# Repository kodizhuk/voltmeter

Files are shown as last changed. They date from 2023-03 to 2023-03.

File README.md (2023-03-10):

# Voltmeter for the power supply
Simple voltmeter on the DA14858 microcontroller
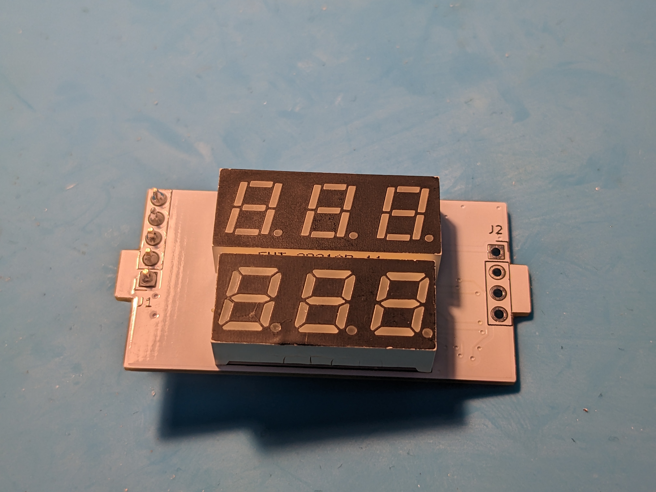
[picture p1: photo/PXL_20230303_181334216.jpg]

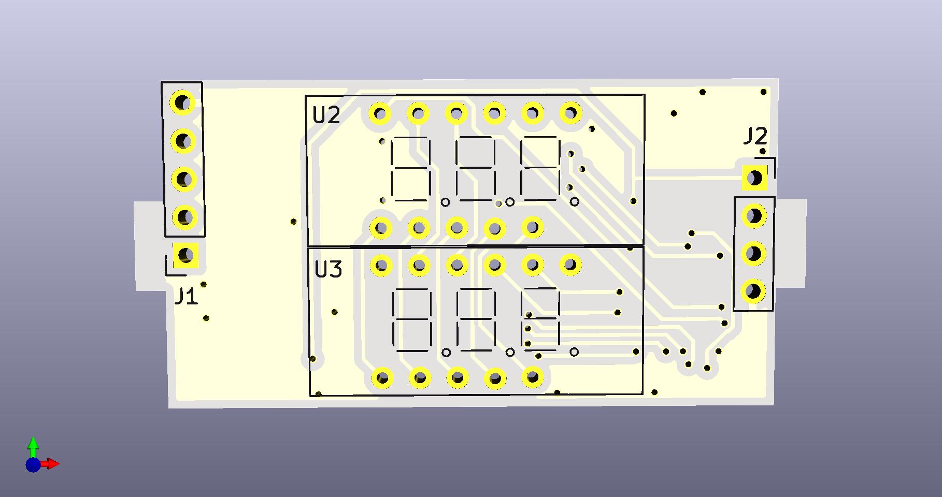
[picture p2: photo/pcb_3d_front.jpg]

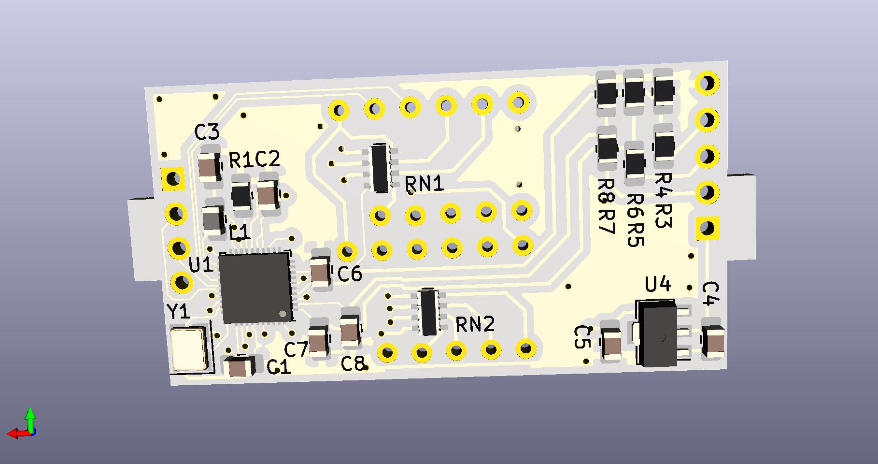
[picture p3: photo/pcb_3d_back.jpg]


## Short description
The three channels ADC are used to measure voltage, current and the potentiometer value (that changed the current limit). The voltage and current are displayed if the potentiometer value isn't changing. If the potentiomter values is changed, the current limit value is displayed instead of the current.

## Schematic
PCB is created using KiKad software
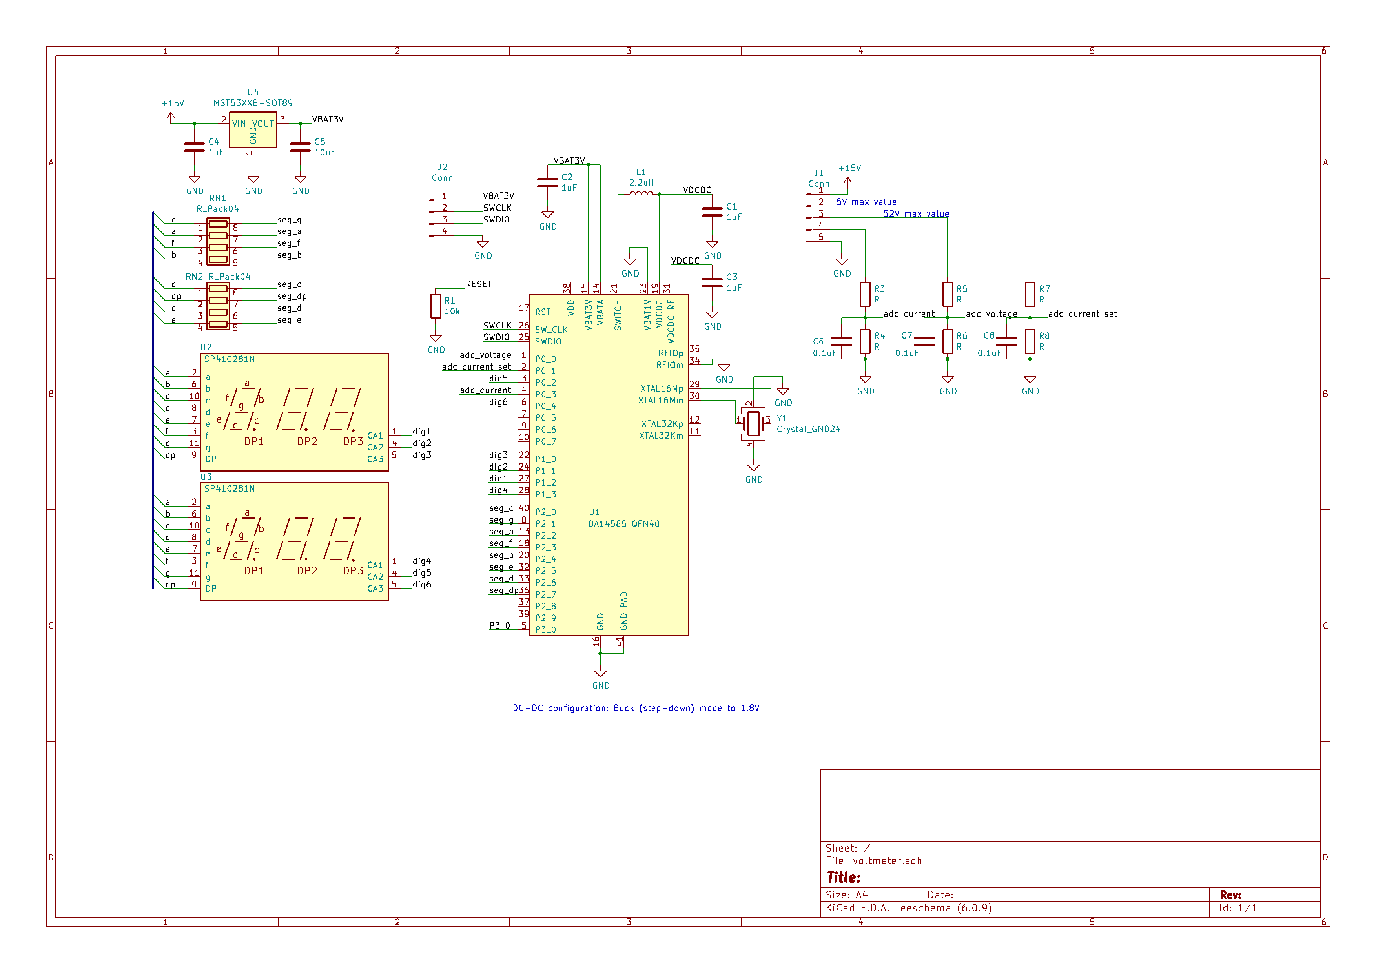
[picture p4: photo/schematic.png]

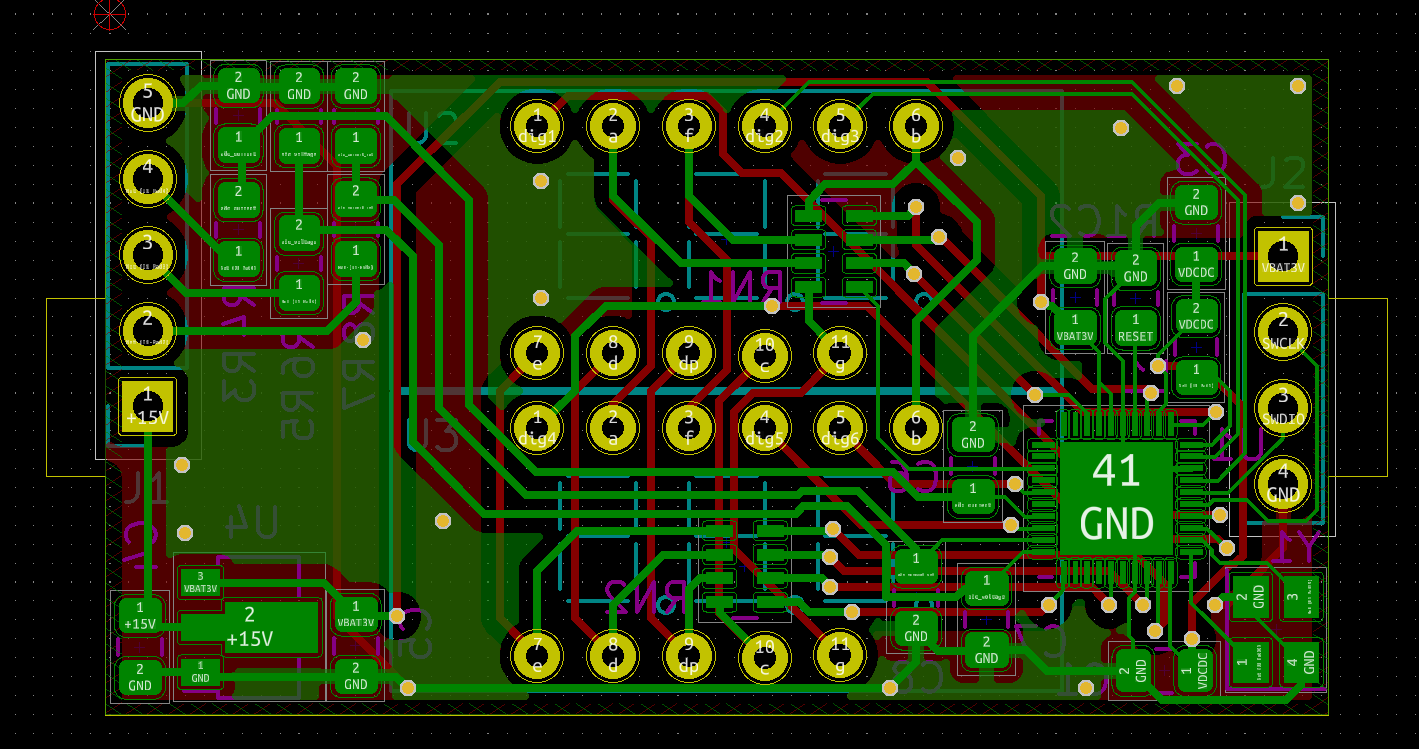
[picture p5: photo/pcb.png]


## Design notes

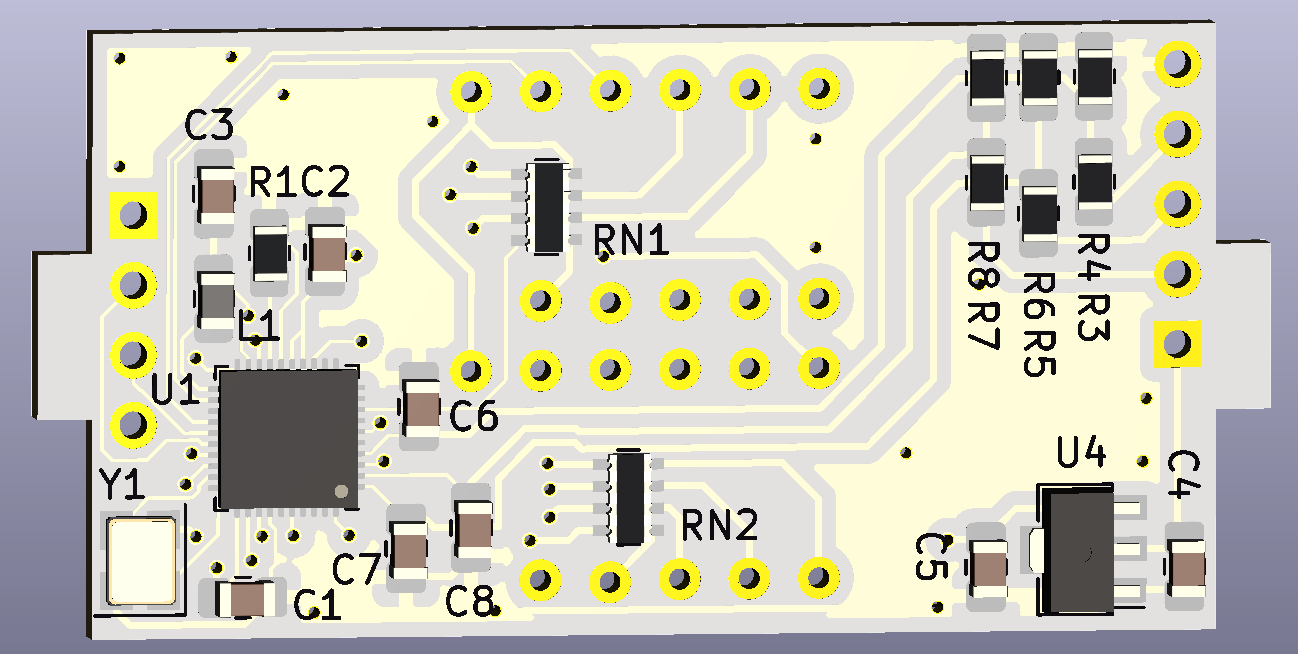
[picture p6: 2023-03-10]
photo/pcb_3d_back.png

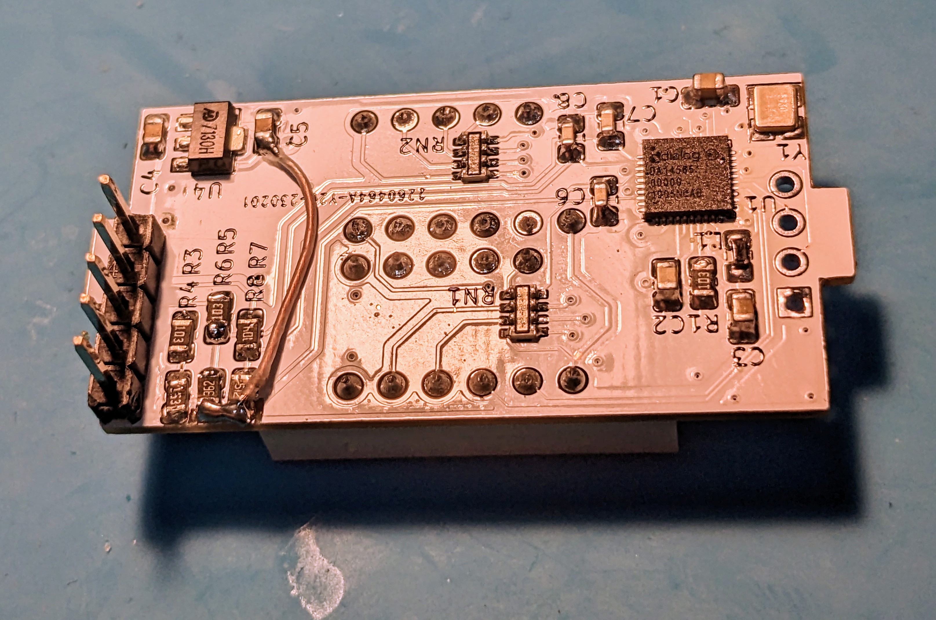
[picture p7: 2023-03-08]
photo/PXL_20230303_181327245~2.jpg

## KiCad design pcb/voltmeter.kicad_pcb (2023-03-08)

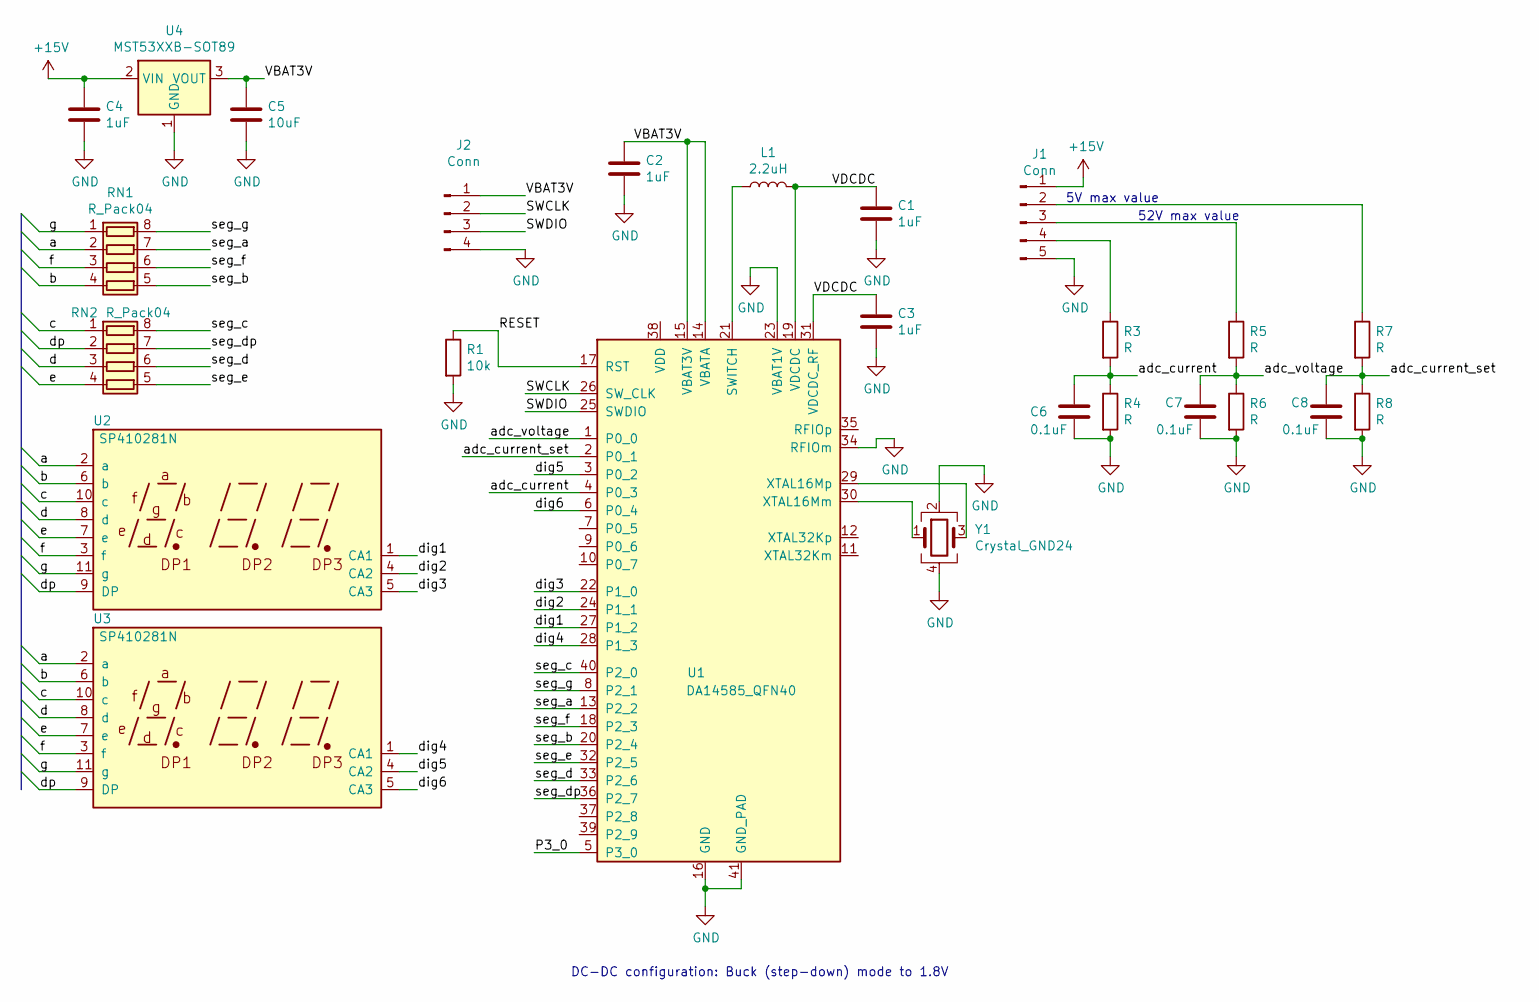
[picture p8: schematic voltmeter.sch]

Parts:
C1, C2, C3, C4: 1uF; C_0805_2012Metric_Pad1.18x1.45mm_HandSolder
C5: 10uF; C_0805_2012Metric_Pad1.18x1.45mm_HandSolder
C6, C7, C8: 0.1uF; C_0805_2012Metric_Pad1.18x1.45mm_HandSolder
J1: Conn; PinSocket_1x05_P2.54mm_Vertical
J2: Conn; PinSocket_1x04_P2.54mm_Vertical
L1: 2.2uH; L_0805_2012Metric_Pad1.15x1.40mm_HandSolder
R1: 10k; R_0805_2012Metric_Pad1.20x1.40mm_HandSolder
R3, R4, R5, R6, R7, R8: R; R_0805_2012Metric_Pad1.20x1.40mm_HandSolder
RN1, RN2: R_Pack04; R_Array_Concave_4x0603
U1: DA14585_QFN40; QFN-40-1EP_5x5mm_P0.4mm_EP3.8x3.8mm
U2, U3: SP410281N; 7_seg_0.28in_display
U4: MST53XXB-SOT89; SOT-89-3
Y1: Crystal_GND24; Crystal_SMD_3225-4Pin_3.2x2.5mm

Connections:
+15V: C4.1, J1.1, U4.2 (VIN)
/P3_0: U1.5 (P3_0)
/RESET: R1.1, U1.17 (RST)
/SWCLK: J2.2, U1.26 (SW_CLK)
/SWDIO: J2.3, U1.25 (SWDIO)
/VBAT3V: C2.1, C5.1, J2.1, U1.14 (VBATA), U1.15 (VBAT3V), U4.3 (VOUT)
/VDCDC: C1.1, C3.1, L1.2, U1.19 (VDCDC), U1.31 (VDCDC_RF)
/a: RN1.2 (R2.1), U2.2 (a), U3.2 (a)
/adc_current: C6.1, R3.2, R4.1, U1.4 (P0_3)
/adc_current_set: C8.1, R7.2, R8.1, U1.2 (P0_1)
/adc_voltage: C7.1, R5.2, R6.1, U1.1 (P0_0)
/b: RN1.4 (R4.1), U2.6 (b), U3.6 (b)
/c: RN2.1 (R1.1), U2.10 (c), U3.10 (c)
/d: RN2.3 (R3.1), U2.8 (d), U3.8 (d)
/dig1: U1.27 (P1_2), U2.1 (CA1)
/dig2: U1.24 (P1_1), U2.4 (CA2)
/dig3: U1.22 (P1_0), U2.5 (CA3)
/dig4: U1.28 (P1_3), U3.1 (CA1)
/dig5: U1.3 (P0_2), U3.4 (CA2)
/dig6: U1.6 (P0_4), U3.5 (CA3)
/dp: RN2.2 (R2.1), U2.9 (DP), U3.9 (DP)
/e: RN2.4 (R4.1), U2.7 (e), U3.7 (e)
/f: RN1.3 (R3.1), U2.3 (f), U3.3 (f)
/g: RN1.1 (R1.1), U2.11 (g), U3.11 (g)
/seg_a: RN1.7 (R2.2), U1.13 (P2_2)
/seg_b: RN1.5 (R4.2), U1.20 (P2_4)
/seg_c: RN2.8 (R1.2), U1.40 (P2_0)
/seg_d: RN2.6 (R3.2), U1.33 (P2_6)
/seg_dp: RN2.7 (R2.2), U1.36 (P2_7)
/seg_e: RN2.5 (R4.2), U1.32 (P2_5)
/seg_f: RN1.6 (R3.2), U1.18 (P2_3)
/seg_g: RN1.8 (R1.2), U1.8 (P2_1)
GND: C1.2, C2.2, C3.2, C4.2, C5.2, C6.2, C7.2, C8.2, J1.5, J2.4, R1.2, R4.2, R6.2, R8.2, U1.16 (GND), U1.23 (VBAT1V), U1.34 (RFIOm), U1.41 (GND_PAD), U4.1 (GND), Y1.2, Y1.4
unnamed: J1.2, R7.1
unnamed: J1.3, R5.1
unnamed: J1.4, R3.1
unnamed: L1.1, U1.21 (SWITCH)
unnamed: U1.29 (XTAL16Mp), Y1.3
unnamed: U1.30 (XTAL16Mm), Y1.1

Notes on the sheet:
DC-DC configuration: Buck (step-down) mode to 1.8V
5V max value
52V max value

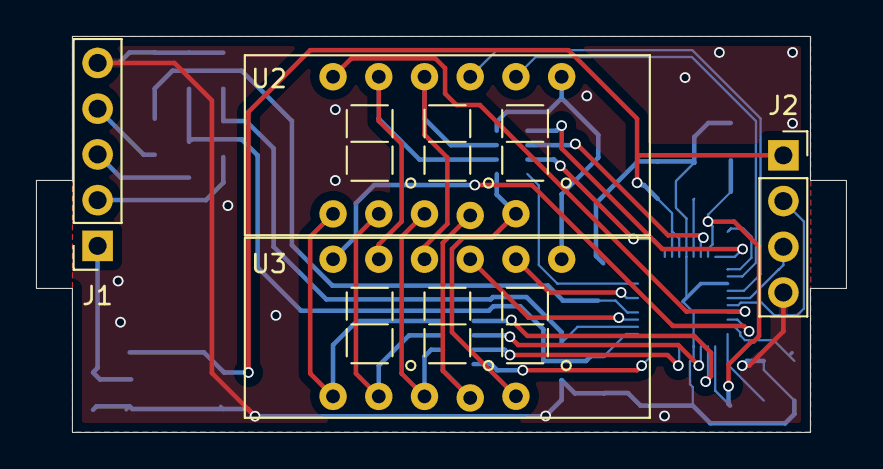
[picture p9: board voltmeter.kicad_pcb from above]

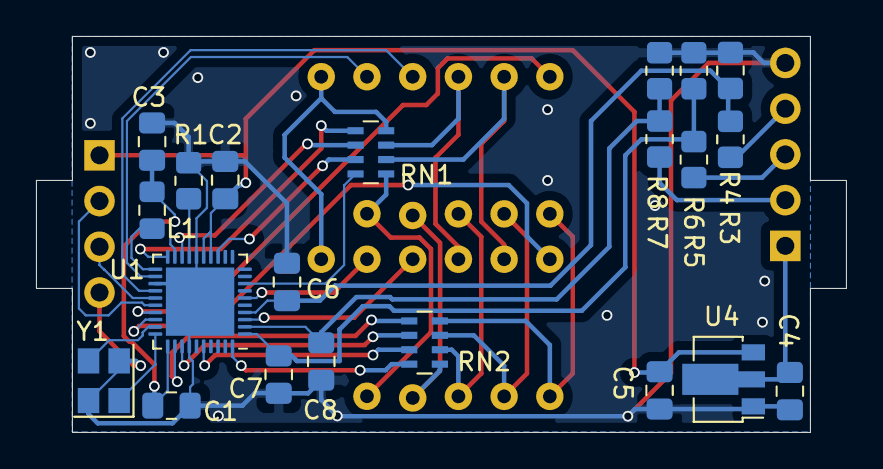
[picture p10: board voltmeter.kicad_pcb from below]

Board: 2 copper layers, 45.0 x 22.0 mm, 25 parts (21 on the bottom side), 38 nets.

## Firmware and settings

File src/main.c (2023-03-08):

/**
 ****************************************************************************************
 *
 * @file main.c
 *
 * @brief Battery level example
 *
 * Copyright (C) 2012-2019 Dialog Semiconductor.
 * This computer program includes Confidential, Proprietary Information
 * of Dialog Semiconductor. All Rights Reserved.
 *
 ****************************************************************************************
 */
 
//#define DEBUG_ON
 
#include <stdio.h>
#include "arch_system.h"
#include "user_periph_setup.h"
#include "gpio.h"
#ifdef DEBUG_ON
	#include "uart.h"
	#include "uart_utils.h"
#endif
#include "datasheet.h"
#if defined (__DA14531__)
#include "hw_otpc.h"
#include "syscntl.h"
#include "otp_hdr.h"
#include "otp_cs.h"
#include "arch.h"
#endif

//added
#include "adc.h"
#include "systick.h"
#include "adc_read.h"
#include "display.h"

#define SYSTICK_PERIOD_US   500000     // period for systick timer in us, so 500000 ticks = .5 second
#define SYSTICK_EXCEPTION   1           // generate systick exceptions
#define POT_THRESHOLD				0.5					//threshold for potentimeter, 0.5A value
#define POT_TIME						8

static float voltage, current, potentiometer;
static uint8_t systic_timer_done;

/**
 ****************************************************************************************
 * @brief SysTick ISR routine
 ****************************************************************************************
 */
static void systick_isr(void)
{
	systic_timer_done = 1;
}


/**
 ****************************************************************************************
 * @brief Main routine of the battery level example
 ****************************************************************************************
 */
int main (void)
{
	system_init();
	
	adc_channels_init();
	display_init();
	
	systick_register_callback(systick_isr);
	// Systick will be initialized to use a reference clock frequency of 1 MHz
	systick_start(SYSTICK_PERIOD_US, SYSTICK_EXCEPTION);

	#ifdef DEBUG_ON
		printf_string(UART, "\n\r\n\r");
		printf_string(UART, "*******************\n\r");
		printf_string(UART, "* Voltage read *\n\r");
		printf_string(UART, "*******************\n\r");
	#endif
	
	
	while(1)
	{
		static uint16_t timer_for_pot_value = POT_TIME;
		
		if(systic_timer_done)
		{
			adc_read_volt_curr(&voltage, &current, &potentiometer); 
			
			static float prev_pot_value;
			if((potentiometer > (prev_pot_value+POT_THRESHOLD) ||
			potentiometer < (prev_pot_value-POT_THRESHOLD) ) || timer_for_pot_value < POT_TIME){
					display_update(voltage, potentiometer);
					prev_pot_value = potentiometer;
					timer_for_pot_value --;
			}else {
				display_update(voltage, current);
				timer_for_pot_value = POT_TIME;
			}
			
			#ifdef DEBUG_ON
				char uart_buffer [10];
				sprintf(uart_buffer, "OUT 0_0: %.1f V\n\r", voltage/100);
				printf_string(UART, uart_buffer);
				sprintf(uart_buffer, "OUT 0_3: %.1f A\n\r", current/100);
				printf_string(UART, uart_buffer);
			#endif
			
			systic_timer_done = 0;
		}
	}
}

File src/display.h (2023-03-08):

#ifndef DISPLAY

#define DISPLAY
#include "stdint.h"
#include "gpio.h"

//segments, J7 connector
// segA  - P2_2
// segB  - P2_4
// segC  - P2_0
// segD  - P2_6-
// segE  - P2_5-
// segF  - P2_3
// segG  - P2_1
// segDP - P2_7
#define PORT_SEGMENT GPIO_PORT_2
#define PIN_A GPIO_PIN_2
#define PIN_B GPIO_PIN_4
#define PIN_C GPIO_PIN_0
#define PIN_D GPIO_PIN_6
#define PIN_E GPIO_PIN_5
#define PIN_F GPIO_PIN_3
#define PIN_G GPIO_PIN_1
#define PIN_DP GPIO_PIN_7

//digits
// dig0 - P1_2
// dig1 - P1_1
// dig2 - P1_0
// dig3 - P1_3
// dig4 - P0_2
// dig5 - P0_4
#define PORT_DIG0 GPIO_PORT_1
#define PIN_DIG0 GPIO_PIN_2
#define PORT_DIG1 GPIO_PORT_1
#define PIN_DIG1 GPIO_PIN_1
#define PORT_DIG2 GPIO_PORT_1
#define PIN_DIG2 GPIO_PIN_0
#define PORT_DIG3 GPIO_PORT_1
#define PIN_DIG3 GPIO_PIN_3
#define PORT_DIG4 GPIO_PORT_0
#define PIN_DIG4 GPIO_PIN_2
#define PORT_DIG5 GPIO_PORT_0
#define PIN_DIG5 GPIO_PIN_4

void display_init(void);
void display_update(float num1, float num2);

#endif

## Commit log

2023-03-08 add pcb files
    [voltmeter-B_Cu.gbl, voltmeter-B_Mask.gbs, voltmeter-B_Paste.gbp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]
2023-03-08 add schematic
2023-03-08 add pcb
2023-03-08 added pcb
